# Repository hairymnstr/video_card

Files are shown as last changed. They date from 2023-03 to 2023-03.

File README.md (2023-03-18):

# ECB Video Card

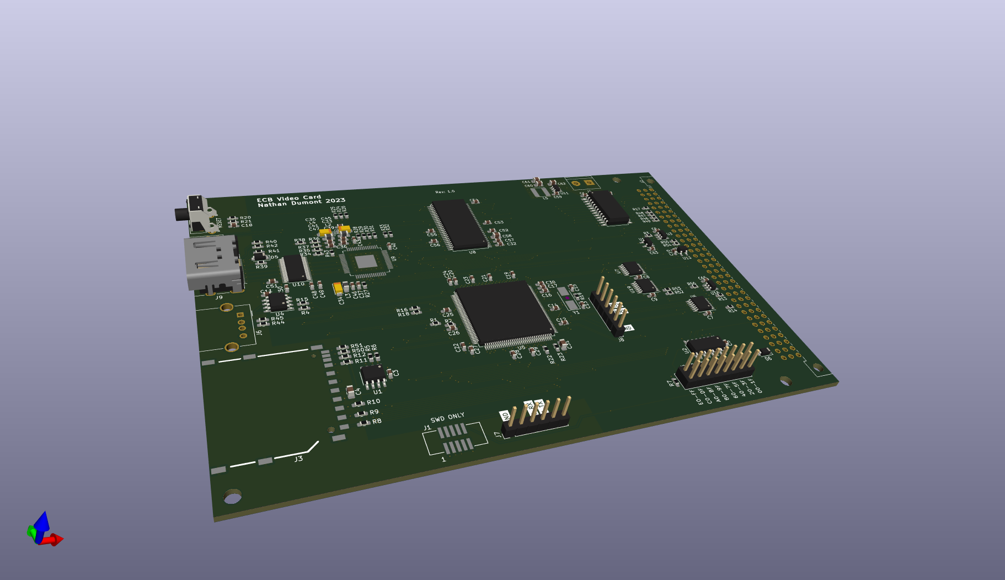
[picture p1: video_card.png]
A screenshot of a PCB with HDMI connector and various SMD chips


This is a project to create a working HDMI output video card for an ECB based 8 bit computer.  The general plan is to use this card with a Z80/Z180 based processor card and a backplane of some sort.  As far as I can see it's compatible with standard ECB layout and will probably work with other modern-retro computers.  It will probably work perfectly well as a standalone ARM based computer.

## Specs

A brief description of the board's features:

* STM32F429 ARM Cortex-M4 at 180MHz
* Hardware support for 2D DMA and graphics related operations
* 32MB (16M x 16) SDRAM at 90MHz for framebuffer and image storage
* USB host port via a single USB-A socket up to full-speed (12Mbps)
* SD card socket via SPI interface
* Two UART headers for 3.3V level interface
* 8 bit data bus interface
  * Mapped into 32 registers of the I/O address space
  * Selectable to any combination of the top 3 bits of the 8 bit IO bus
  * Support for interrupt generation including IEI/IEO cascading support
  * Can operate in Z80 mode-2 because the interrupt ack is mapped to an interrupt on the STM32

## Architecture

The core of the board is the STM32F429 which supports an LCD TFT controller which is outputting the hardware sync signals and the 3 colour channels as parallel data.  The pinout of the chip in use (only one I can currently get) limits the colour depth to 18 bits.  The LCD TFT interface is connected to a TI TFP410 HDMI/DVI transmitter chip which converts the parallel colour data and sync signals to differential data and clock for HDMI devices.  There's also an ESD protection chip on the HDMI output.

## Status

So far this is just a design, I've been messing around with these parts and designs for a few years but part availability and time have so far prevented me from building and testing it.  Hopefully in the near future I can get a board made and try it.

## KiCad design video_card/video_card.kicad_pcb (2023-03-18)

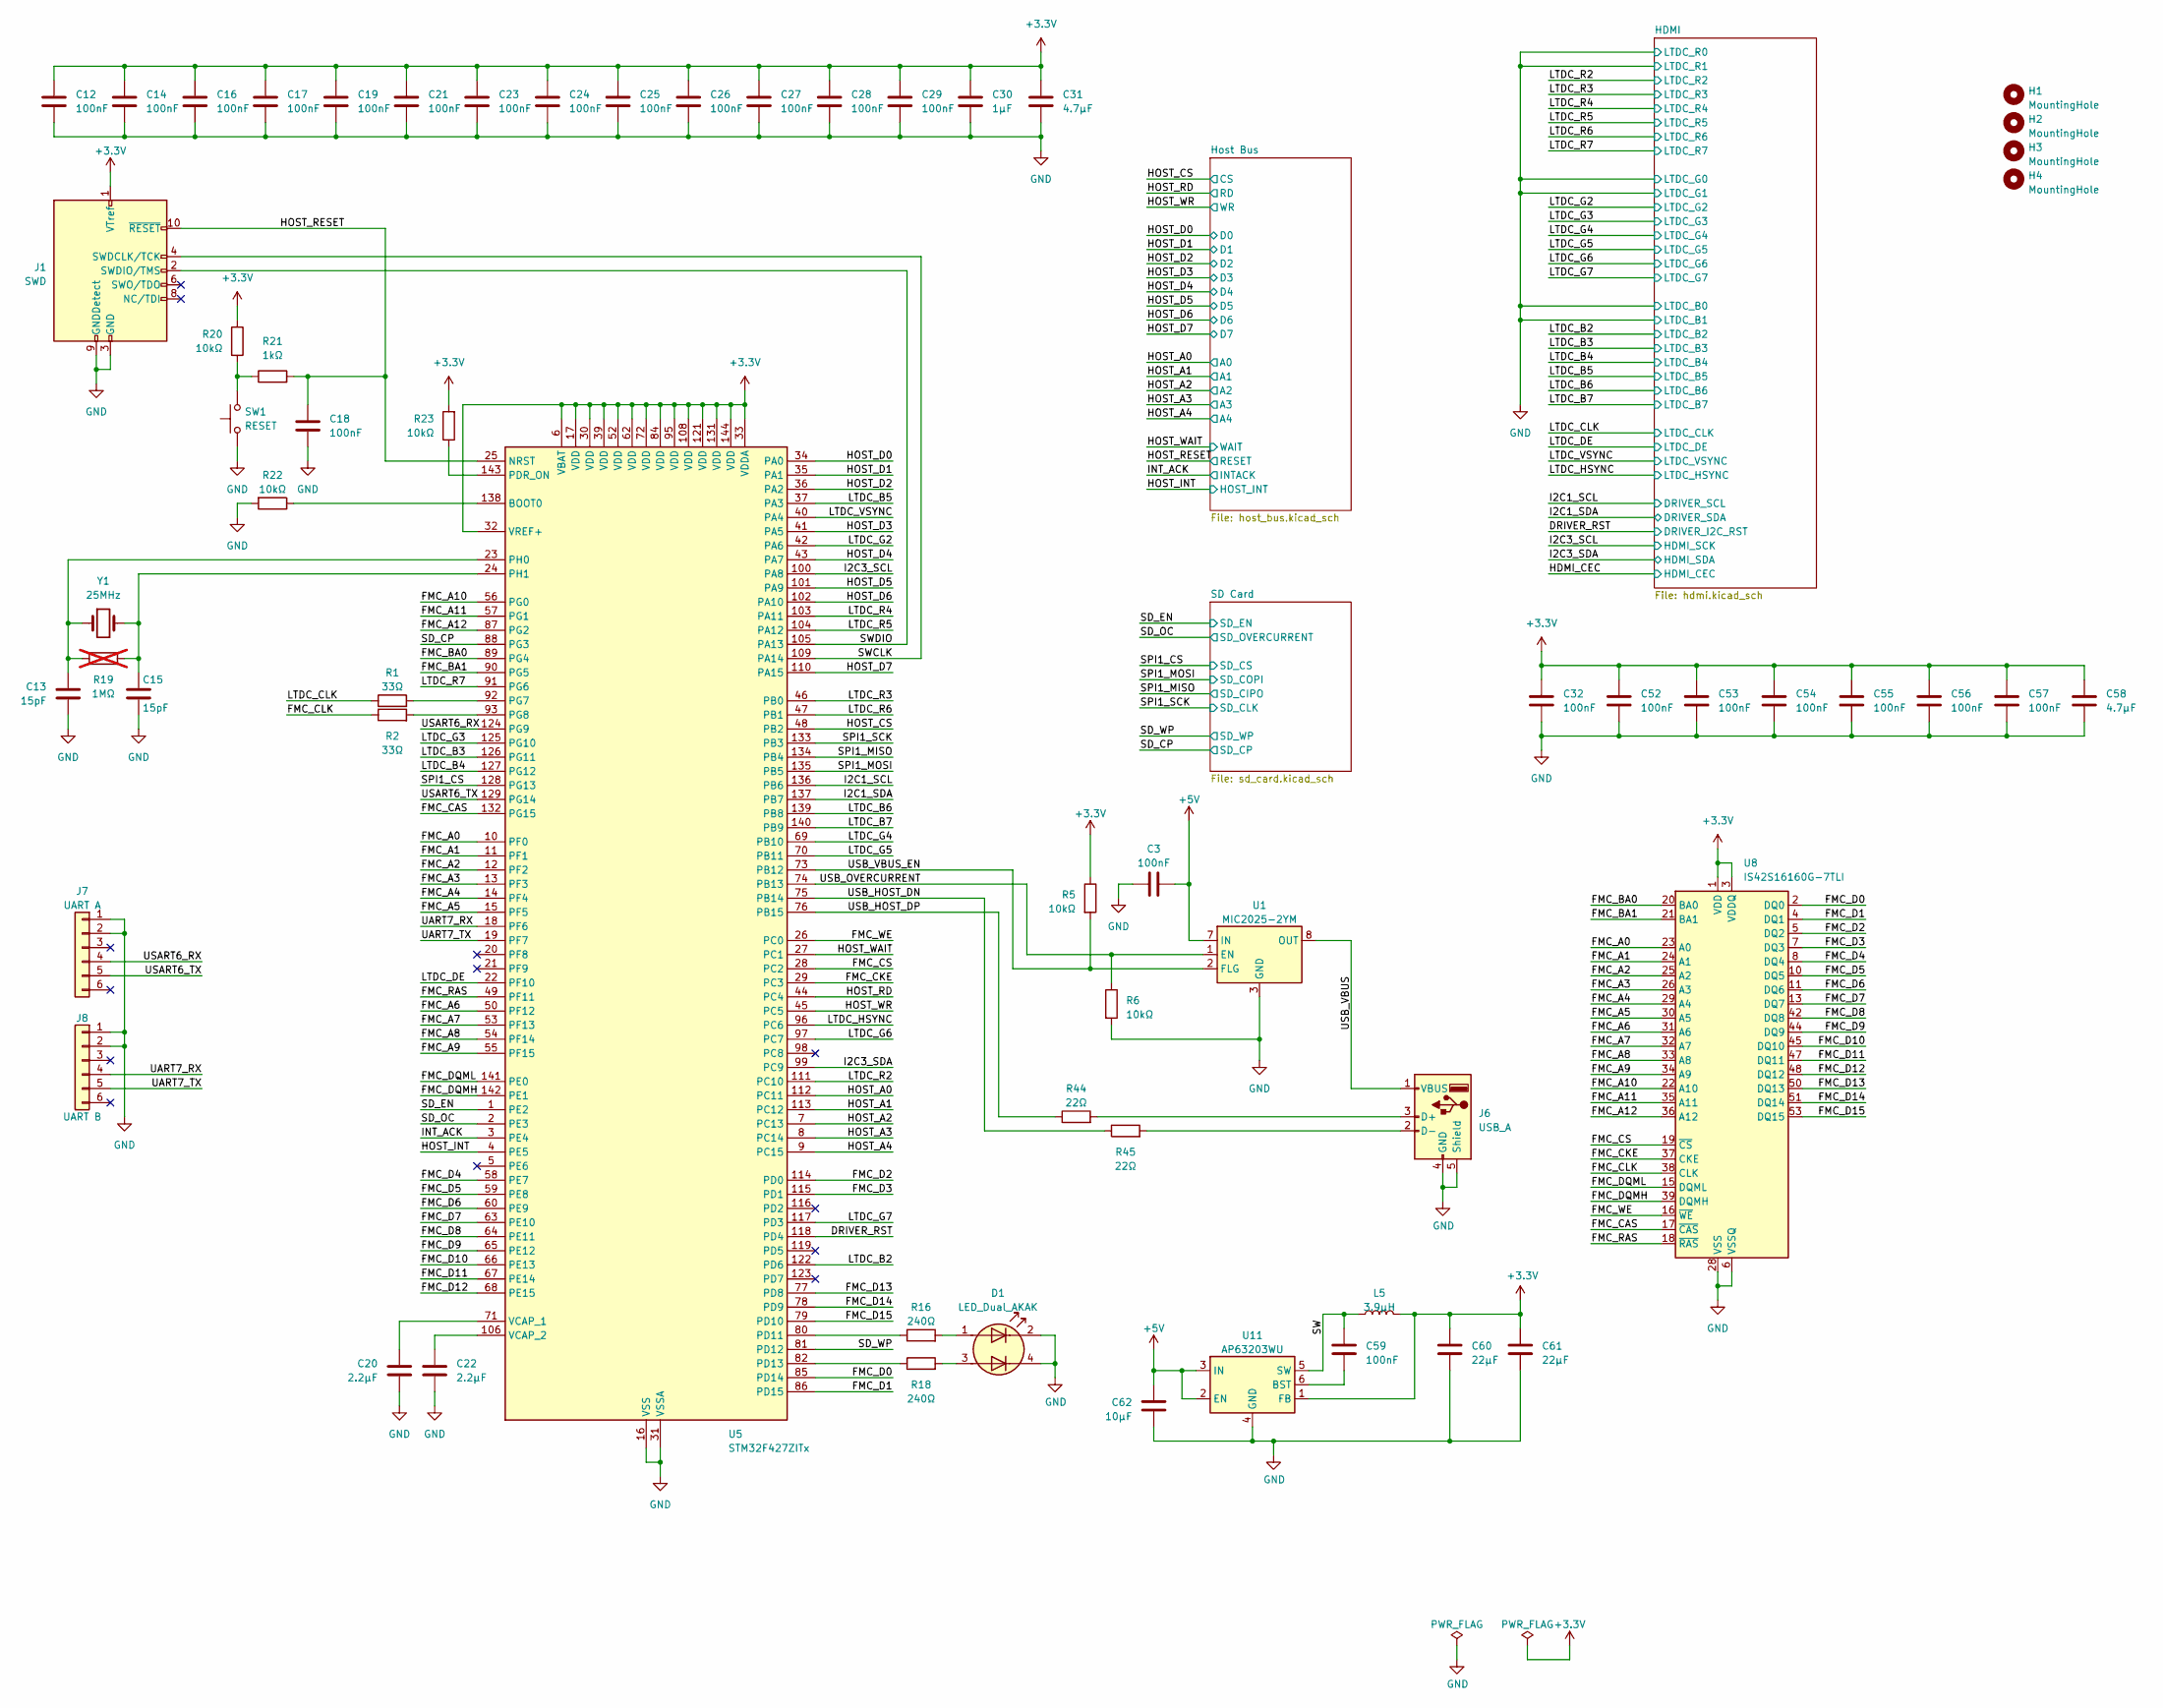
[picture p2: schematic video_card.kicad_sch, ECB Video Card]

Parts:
C3, C12, C14, C16, C17, C18, C19, C21, C23, C24, C25, C26, C27, C28, C29, C32, C52, C53, C54, C55, C56, C57, C59: 100nF; C_0603_1608Metric_Pad1.08x0.95mm_HandSolder; Part number Generic 0603 X7R 50V 10%
C13, C15: 15pF; C_0603_1608Metric_Pad1.08x0.95mm_HandSolder
C20, C22: 2.2µF; C_0603_1608Metric_Pad1.08x0.95mm_HandSolder
C30: 1µF; C_0603_1608Metric_Pad1.08x0.95mm_HandSolder
C31, C58: 4.7µF; C_0805_2012Metric_Pad1.18x1.45mm_HandSolder
C60, C61: 22µF; C_0805_2012Metric_Pad1.18x1.45mm_HandSolder
C62: 10µF; C_0805_2012Metric_Pad1.18x1.45mm_HandSolder
D1: LED_Dual_AKAK; LED_KINGBRIGHT_STACKED
H1, H2, H3, H4: MountingHole; MountingHole_3.2mm_M3
J1: SWD; SAMTEC_SHF-SM_5x2
J6: USB_A; USB_A_Molex_67643_Horizontal
J7: UART A; PinHeader_1x06_P2.54mm_Vertical
J8: UART B; PinHeader_1x06_P2.54mm_Vertical
L5: 3.9µH; Inductor_WE_LQS; Farnell 3517075
R1, R2: 33Ω; R_0603_1608Metric_Pad0.98x0.95mm_HandSolder
R5, R6, R20, R22, R23: 10kΩ; R_0603_1608Metric_Pad0.98x0.95mm_HandSolder
R16, R18: 240Ω; R_0603_1608Metric_Pad0.98x0.95mm_HandSolder
R19: 1MΩ; R_0603_1608Metric_Pad0.98x0.95mm_HandSolder; not fitted
R21: 1kΩ; R_0603_1608Metric_Pad0.98x0.95mm_HandSolder
R44, R45: 22Ω; R_0603_1608Metric_Pad0.98x0.95mm_HandSolder
SW1: RESET; SW_Tactile_SPST_Angled_PTS645Vx58-2LFS
U1: MIC2025-2YM; SOIC-8_3.9x4.9mm_P1.27mm
U5: STM32F427ZITx; LQFP-144_20x20mm_P0.5mm
U8: IS42S16160G-7TLI; TSOP-II-54_22.2x10.16mm_P0.8mm
U11: AP63203WU; TSOT-23-6
Y1: 25MHz; Crystal_SMD_Abracon_ABM3-2Pin_5.0x3.2mm_HandSoldering; Farnell 2101328

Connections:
/DRIVER_RST: U5.118 (PD4); also elsewhere on the board
/FMC_A0: U5.10 (PF0), U8.23 (A0)
/FMC_A1: U5.11 (PF1), U8.24 (A1)
/FMC_A2: U5.12 (PF2), U8.25 (A2)
/FMC_A3: U5.13 (PF3), U8.26 (A3)
/FMC_A4: U5.14 (PF4), U8.29 (A4)
/FMC_A5: U5.15 (PF5), U8.30 (A5)
/FMC_A6: U5.50 (PF12), U8.31 (A6)
/FMC_A7: U5.53 (PF13), U8.32 (A7)
/FMC_A8: U5.54 (PF14), U8.33 (A8)
/FMC_A9: U5.55 (PF15), U8.34 (A9)
/FMC_A10: U5.56 (PG0), U8.22 (A10)
/FMC_A11: U5.57 (PG1), U8.35 (A11)
/FMC_A12: U5.87 (PG2), U8.36 (A12)
/FMC_BA0: U5.89 (PG4), U8.20 (BA0)
/FMC_BA1: U5.90 (PG5), U8.21 (BA1)
/FMC_CAS: U5.132 (PG15), U8.17 (~CAS)
/FMC_CKE: U5.29 (PC3), U8.37 (CKE)
/FMC_CLK: R2.1, U8.38 (CLK)
/FMC_CS: U5.28 (PC2), U8.19 (~CS)
/FMC_D0: U5.85 (PD14), U8.2 (DQ0)
/FMC_D1: U5.86 (PD15), U8.4 (DQ1)
/FMC_D2: U5.114 (PD0), U8.5 (DQ2)
/FMC_D3: U5.115 (PD1), U8.7 (DQ3)
/FMC_D4: U5.58 (PE7), U8.8 (DQ4)
/FMC_D5: U5.59 (PE8), U8.10 (DQ5)
/FMC_D6: U5.60 (PE9), U8.11 (DQ6)
/FMC_D7: U5.63 (PE10), U8.13 (DQ7)
/FMC_D8: U5.64 (PE11), U8.42 (DQ8)
/FMC_D9: U5.65 (PE12), U8.44 (DQ9)
/FMC_D10: U5.66 (PE13), U8.45 (DQ10)
/FMC_D11: U5.67 (PE14), U8.47 (DQ11)
/FMC_D12: U5.68 (PE15), U8.48 (DQ12)
/FMC_D13: U5.77 (PD8), U8.50 (DQ13)
/FMC_D14: U5.78 (PD9), U8.51 (DQ14)
/FMC_D15: U5.79 (PD10), U8.53 (DQ15)
/FMC_DQMH: U5.142 (PE1), U8.39 (DQMH)
/FMC_DQML: U5.141 (PE0), U8.15 (DQML)
/FMC_RAS: U5.49 (PF11), U8.18 (~RAS)
/FMC_WE: U5.26 (PC0), U8.16 (~WE)
/HOST_A0: U5.112 (PC11); also elsewhere on the board
/HOST_A1: U5.113 (PC12); also elsewhere on the board
/HOST_A2: U5.7 (PC13); also elsewhere on the board
/HOST_A3: U5.8 (PC14); also elsewhere on the board
/HOST_A4: U5.9 (PC15); also elsewhere on the board
/HOST_CS: U5.48 (PB2); also elsewhere on the board
/HOST_D0: U5.34 (PA0); also elsewhere on the board
/HOST_D1: U5.35 (PA1); also elsewhere on the board
/HOST_D2: U5.36 (PA2); also elsewhere on the board
/HOST_D3: U5.41 (PA5); also elsewhere on the board
/HOST_D4: U5.43 (PA7); also elsewhere on the board
/HOST_D5: U5.101 (PA9); also elsewhere on the board
/HOST_D6: U5.102 (PA10); also elsewhere on the board
/HOST_D7: U5.110 (PA15); also elsewhere on the board
/HOST_INT: U5.4 (PE5); also elsewhere on the board
/HOST_RD: U5.44 (PC4); also elsewhere on the board
/HOST_RESET: C18.1, J1.10 (~RESET), R21.2, U5.25 (NRST); also elsewhere on the board
/HOST_WAIT: U5.27 (PC1); also elsewhere on the board
/HOST_WR: U5.45 (PC5); also elsewhere on the board
/I2C1_SCL: U5.136 (PB6); also elsewhere on the board
/I2C1_SDA: U5.137 (PB7); also elsewhere on the board
/I2C3_SCL: U5.100 (PA8); also elsewhere on the board
/I2C3_SDA: U5.99 (PC9); also elsewhere on the board
/INT_ACK: U5.3 (PE4); also elsewhere on the board
/LTDC_B2: U5.122 (PD6); also elsewhere on the board
/LTDC_B3: U5.126 (PG11); also elsewhere on the board
/LTDC_B4: U5.127 (PG12); also elsewhere on the board
/LTDC_B5: U5.37 (PA3); also elsewhere on the board
/LTDC_B6: U5.139 (PB8); also elsewhere on the board
/LTDC_B7: U5.140 (PB9); also elsewhere on the board
/LTDC_CLK: R1.1; also elsewhere on the board
/LTDC_DE: U5.22 (PF10); also elsewhere on the board
/LTDC_G2: U5.42 (PA6); also elsewhere on the board
/LTDC_G3: U5.125 (PG10); also elsewhere on the board
/LTDC_G4: U5.69 (PB10); also elsewhere on the board
/LTDC_G5: U5.70 (PB11); also elsewhere on the board
/LTDC_G6: U5.97 (PC7); also elsewhere on the board
/LTDC_G7: U5.117 (PD3); also elsewhere on the board
/LTDC_HSYNC: U5.96 (PC6); also elsewhere on the board
/LTDC_R2: U5.111 (PC10); also elsewhere on the board
/LTDC_R3: U5.46 (PB0); also elsewhere on the board
/LTDC_R4: U5.103 (PA11); also elsewhere on the board
/LTDC_R5: U5.104 (PA12); also elsewhere on the board
/LTDC_R6: U5.47 (PB1); also elsewhere on the board
/LTDC_R7: U5.91 (PG6); also elsewhere on the board
/LTDC_VSYNC: U5.40 (PA4); also elsewhere on the board
/SD_CP: U5.88 (PG3); also elsewhere on the board
/SD_WP: U5.81 (PD12); also elsewhere on the board
/SPI1_CS: U5.128 (PG13); also elsewhere on the board
/SPI1_MISO: U5.134 (PB4); also elsewhere on the board
/SPI1_MOSI: U5.135 (PB5); also elsewhere on the board
/SPI1_SCK: U5.133 (PB3); also elsewhere on the board
/SW: C59.1, L5.1, U11.5 (SW)
/SWCLK: J1.4 (SWDCLK/TCK), U5.109 (PA14)
/SWDIO: J1.2 (SWDIO/TMS), U5.105 (PA13)
/UART7_RX: J8.4, U5.18 (PF6)
/UART7_TX: J8.5, U5.19 (PF7)
/USART6_RX: J7.4, U5.124 (PG9)
/USART6_TX: J7.5, U5.129 (PG14)
/USB_HOST_DN: R45.1, U5.75 (PB14)
/USB_HOST_DP: R44.1, U5.76 (PB15)
GND: C3.1, C12.2, C13.2, C14.2, C15.2, C16.2, C17.2, C18.2, C19.2, C20.2, C21.2, C22.2, C23.2, C24.2, C25.2, C26.2, C27.2, C28.2, C29.2, C30.2, C31.2, C32.2, C52.2, C53.2, C54.2, C55.2, C56.2, C57.2, C58.2, C60.2, C61.2, C62.2, D1.2 (K1), D1.4 (K2), J1.3 (GND), J1.5 (GND), J1.9 (GNDDetect), J6.4 (GND), J6.5 (Shield), J7.1, J7.2, J8.1, J8.2, R6.2, R22.2, SW1.1, U1.3 (GND), U5.16 (VSS), U5.31 (VSSA), U5.38 (VSS), U5.51 (VSS), U5.61 (VSS), U5.83 (VSS), U5.94 (VSS), U5.107 (VSS), U5.120 (VSS), U5.130 (VSS), U8.6 (VSSQ), U8.12 (VSSQ), U8.28 (VSS), U8.41 (VSS), U8.46 (VSSQ), U8.52 (VSSQ), U8.54 (VSS), U11.4 (GND); also elsewhere on the board
unnamed: D1.1 (A1), R16.2
unnamed: D1.3 (A2), R18.2
unnamed: J6.3 (D+), R44.2
unnamed: J6.2 (D-), R45.2
unnamed: R20.2, R21.1, SW1.2
unnamed: R22.1, U5.138 (BOOT0)
unnamed: R16.1, U5.80 (PD11)
unnamed: R18.1, U5.82 (PD13)
unnamed: R23.1, U5.143 (PDR_ON)
unnamed: R1.2, U5.92 (PG7)
unnamed: R2.2, U5.93 (PG8)
unnamed: C13.1, R19.1, U5.23 (PH0), Y1.1
unnamed: C15.1, R19.2, U5.24 (PH1), Y1.2
unnamed: C20.1, U5.71 (VCAP_1)
unnamed: C22.1, U5.106 (VCAP_2)
unnamed: C59.2, U11.6 (BST)

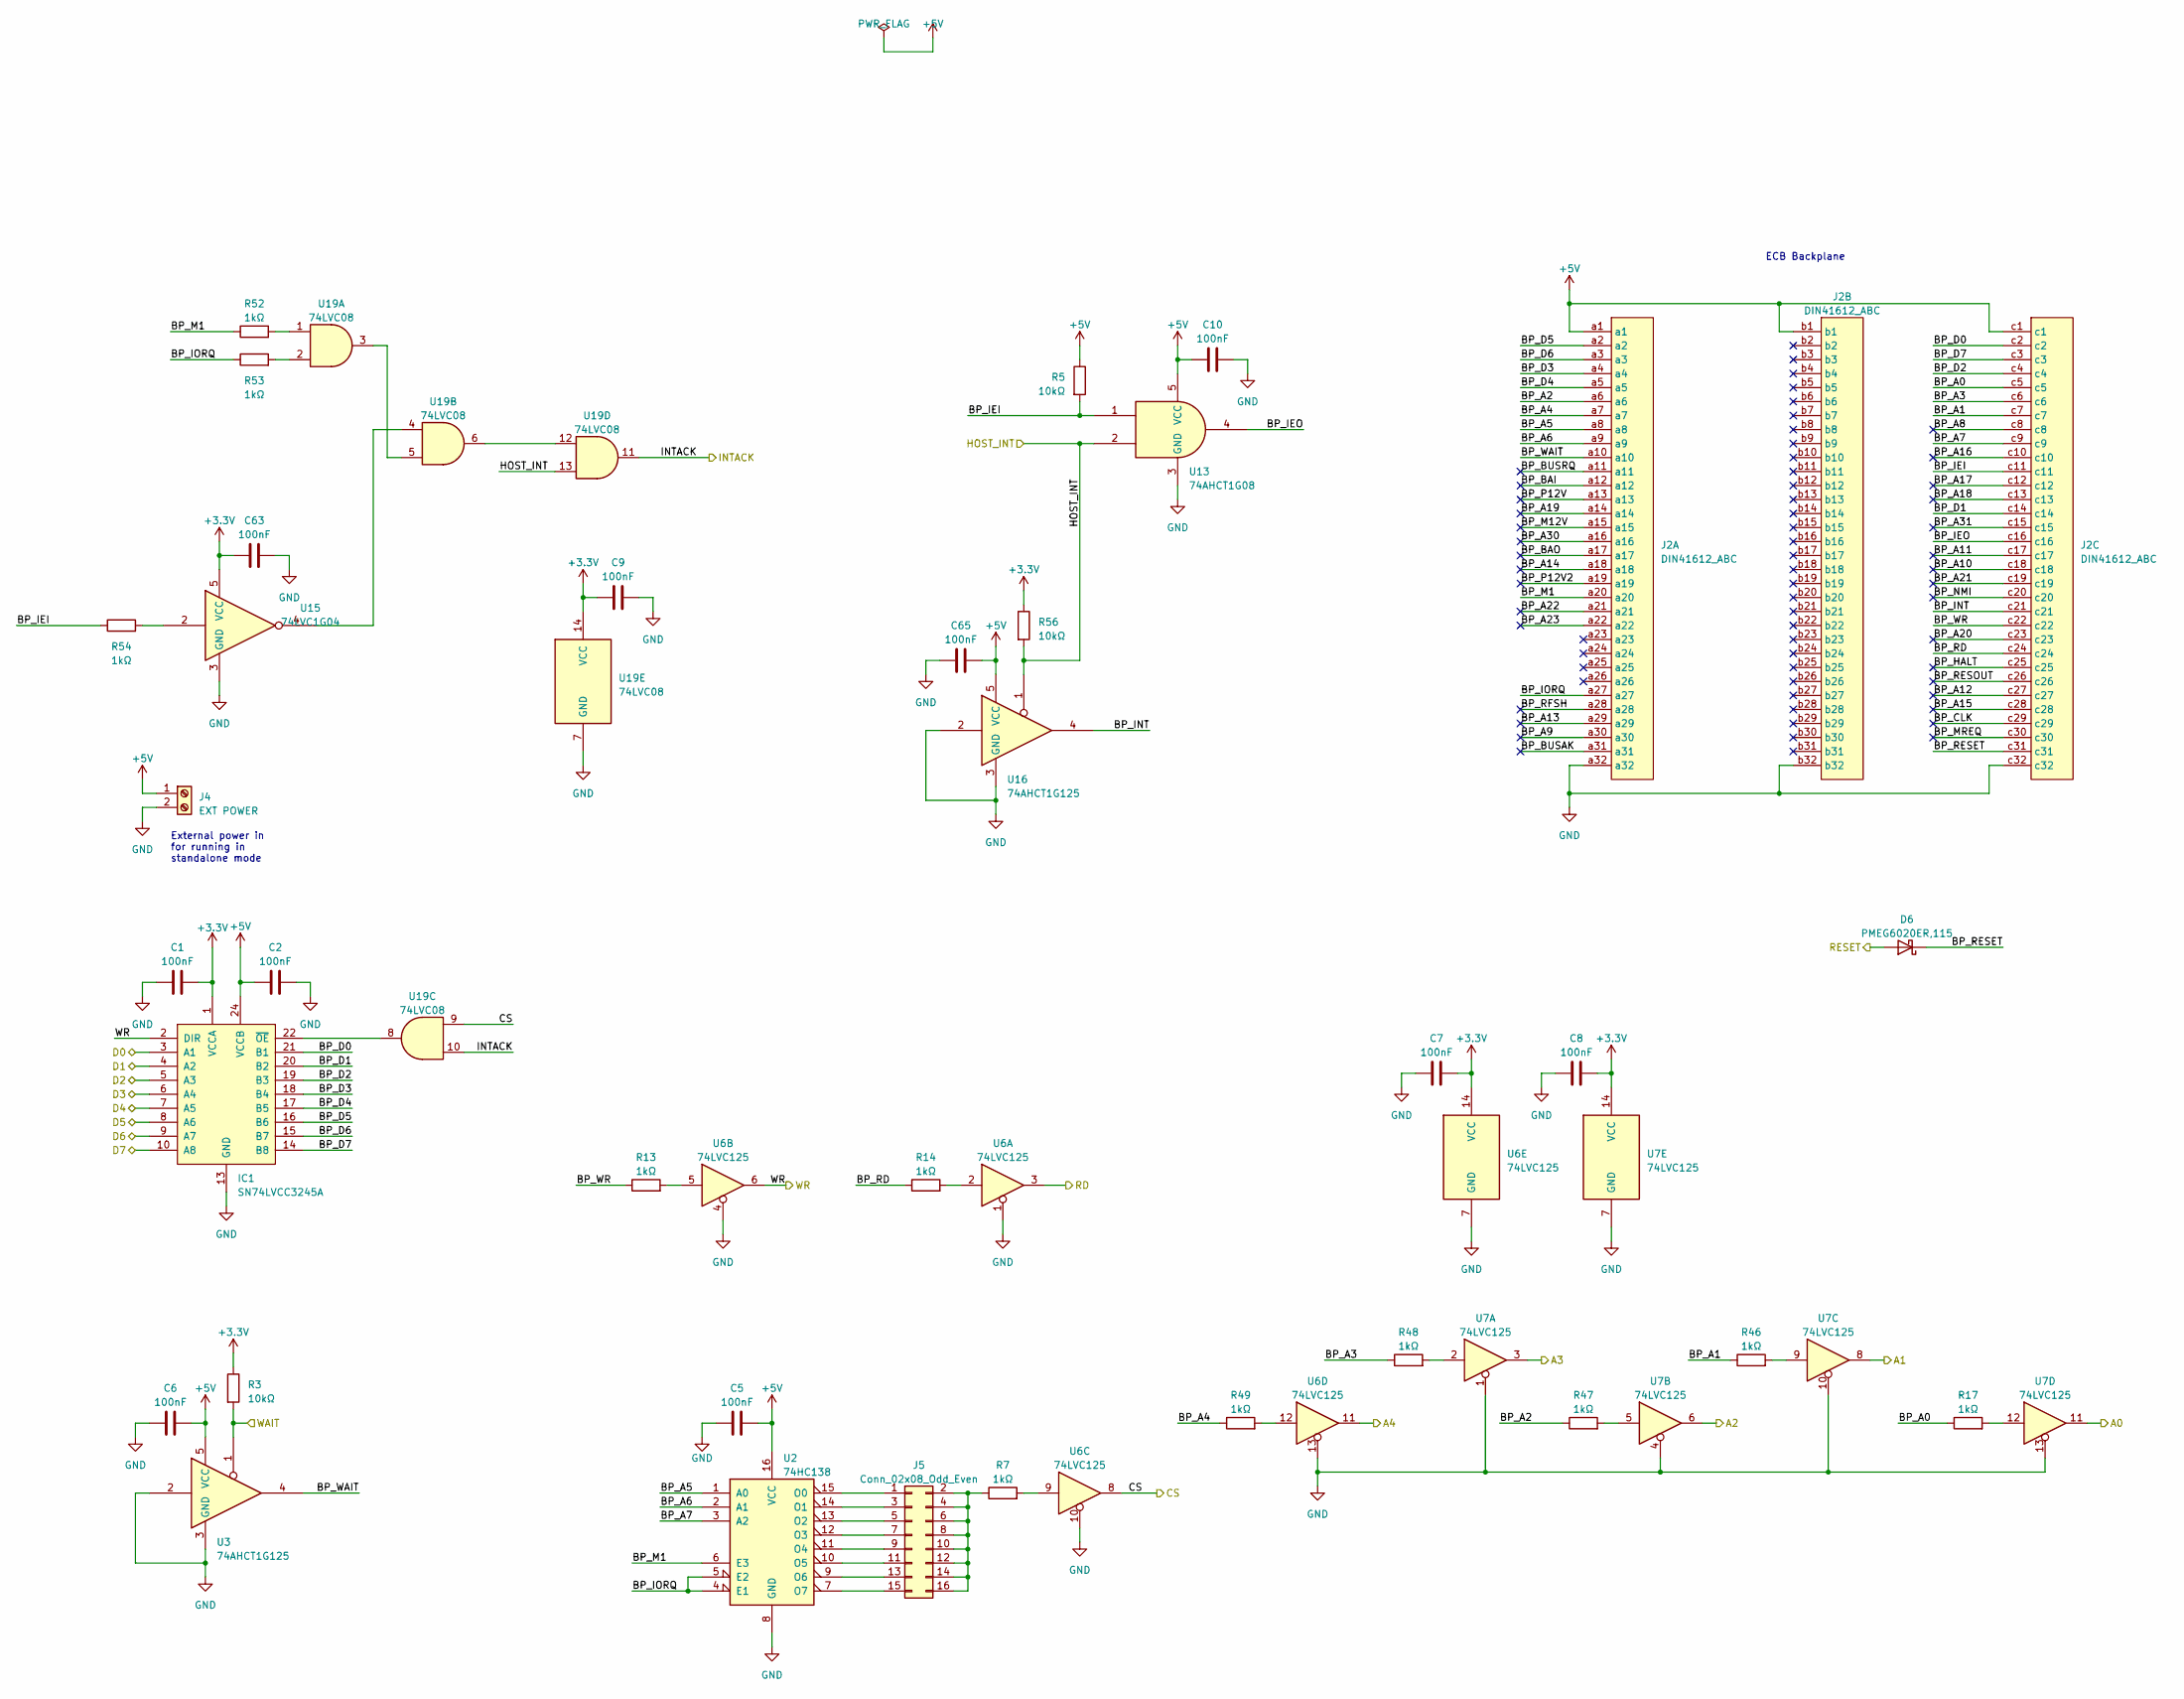
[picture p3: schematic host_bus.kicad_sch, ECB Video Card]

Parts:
C1, C2, C5, C6, C7, C8, C9, C10, C63, C65: 100nF; C_0603_1608Metric_Pad1.08x0.95mm_HandSolder; Part number Generic 0603 X7R 50V 10%
D6: PMEG6020ER,115; D_SOD-123
IC1: SN74LVCC3245A; SOIC-24W_7.5x15.4mm_P1.27mm
J2: DIN41612_ABC; DIN41612_R_3x32_Male_Horizontal_THT
J4: EXT POWER; TerminalBlock_bornier-2_P5.08mm
J5: Conn_02x08_Odd_Even; PinHeader_2x08_P2.54mm_Vertical
R3, R5, R56: 10kΩ; R_0603_1608Metric_Pad0.98x0.95mm_HandSolder
R7, R13, R14, R17, R46, R47, R48, R49, R52, R53, R54: 1kΩ; R_0603_1608Metric_Pad0.98x0.95mm_HandSolder
U2: 74HC138; SOIC-16_3.9x9.9mm_P1.27mm
U3, U16: 74AHCT1G125; SOT-23-5_HandSoldering
U6, U7: 74LVC125; TSSOP-14_4.4x5mm_P0.65mm
U13: 74AHCT1G08; SOT-23-5_HandSoldering
U15: 74LVC1G04; SOT-23-5_HandSoldering
U19: 74LVC08; TSSOP-14_4.4x5mm_P0.65mm

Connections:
/HOST_A0: U7.11; also elsewhere on the board
/HOST_A1: U7.8; also elsewhere on the board
/HOST_A2: U7.6; also elsewhere on the board
/HOST_A3: U7.3; also elsewhere on the board
/HOST_A4: U6.11; also elsewhere on the board
/HOST_CS: U6.8, U19.9; also elsewhere on the board
/HOST_D0: IC1.3 (A1); also elsewhere on the board
/HOST_D1: IC1.4 (A2); also elsewhere on the board
/HOST_D2: IC1.5 (A3); also elsewhere on the board
/HOST_D3: IC1.6 (A4); also elsewhere on the board
/HOST_D4: IC1.7 (A5); also elsewhere on the board
/HOST_D5: IC1.8 (A6); also elsewhere on the board
/HOST_D6: IC1.9 (A7); also elsewhere on the board
/HOST_D7: IC1.10 (A8); also elsewhere on the board
/HOST_INT: R56.2, U13.2, U16.1, U19.13; also elsewhere on the board
/HOST_RD: U6.3; also elsewhere on the board
/HOST_RESET: D6.2 (A); also elsewhere on the board
/HOST_WAIT: R3.2, U3.1; also elsewhere on the board
/HOST_WR: IC1.2 (DIR), U6.6; also elsewhere on the board
/Host Bus/BP_A0: J2.c5, R17.1
/Host Bus/BP_A1: J2.c7, R46.1
/Host Bus/BP_A2: J2.a6, R47.1
/Host Bus/BP_A3: J2.c6, R48.1
/Host Bus/BP_A4: J2.a7, R49.1
/Host Bus/BP_A5: J2.a8, U2.1 (A0)
/Host Bus/BP_A6: J2.a9, U2.2 (A1)
/Host Bus/BP_A7: J2.c9, U2.3 (A2)
/Host Bus/BP_A8: J2.c8
/Host Bus/BP_A9: J2.a30
/Host Bus/BP_A10: J2.c18
/Host Bus/BP_A11: J2.c17
/Host Bus/BP_A12: J2.c27
/Host Bus/BP_A13: J2.a29
/Host Bus/BP_A14: J2.a18
/Host Bus/BP_A15: J2.c28
/Host Bus/BP_A16: J2.c10
/Host Bus/BP_A17: J2.c12
/Host Bus/BP_A18: J2.c13
/Host Bus/BP_A19: J2.a14
/Host Bus/BP_A20: J2.c23
/Host Bus/BP_A21: J2.c19
/Host Bus/BP_A22: J2.a21
/Host Bus/BP_A23: J2.a22
/Host Bus/BP_A30: J2.a16
/Host Bus/BP_A31: J2.c15
/Host Bus/BP_BAI: J2.a12
/Host Bus/BP_BAO: J2.a17
/Host Bus/BP_BUSAK: J2.a31
/Host Bus/BP_BUSRQ: J2.a11
/Host Bus/BP_CLK: J2.c29
/Host Bus/BP_D0: IC1.21 (B1), J2.c2
/Host Bus/BP_D1: IC1.20 (B2), J2.c14
/Host Bus/BP_D2: IC1.19 (B3), J2.c4
/Host Bus/BP_D3: IC1.18 (B4), J2.a4
/Host Bus/BP_D4: IC1.17 (B5), J2.a5
/Host Bus/BP_D5: IC1.16 (B6), J2.a2
/Host Bus/BP_D6: IC1.15 (B7), J2.a3
/Host Bus/BP_D7: IC1.14 (B8), J2.c3
/Host Bus/BP_HALT: J2.c25
/Host Bus/BP_IEO: J2.c16, U13.4
/Host Bus/BP_INT: J2.c21, U16.4
/Host Bus/BP_IORQ: J2.a27, R53.1, U2.4 (E1), U2.5 (E2)
/Host Bus/BP_M1: J2.a20, R52.1, U2.6 (E3)
/Host Bus/BP_M12V: J2.a15
/Host Bus/BP_MREQ: J2.c30
/Host Bus/BP_NMI: J2.c20
/Host Bus/BP_P12V: J2.a13
/Host Bus/BP_P12V2: J2.a19
/Host Bus/BP_RD: J2.c24, R14.1
/Host Bus/BP_RESET: D6.1 (K), J2.c31
/Host Bus/BP_RESOUT: J2.c26
/Host Bus/BP_RFSH: J2.a28
/Host Bus/BP_WAIT: J2.a10, U3.4
/Host Bus/BP_WR: J2.c22, R13.1
/INT_ACK: U19.10, U19.11; also elsewhere on the board
GND: C1.1, C2.2, C5.1, C6.1, C7.1, C8.1, C9.2, C10.2, C63.2, C65.1, IC1.11 (GND), IC1.12 (GND), IC1.13 (GND), J2.a32, J2.b32, J2.c32, J4.2, U2.8 (GND), U3.2, U3.3 (GND), U6.1, U6.4, U6.7 (GND), U6.10, U6.13, U7.1, U7.4, U7.7 (GND), U7.10, U7.13, U13.3 (GND), U15.3 (GND), U16.2, U16.3 (GND), U19.7 (GND); also elsewhere on the board
unnamed: IC1.22 (~OE), U19.8
unnamed: J5.1, U2.15 (O0)
unnamed: J5.3, U2.14 (O1)
unnamed: J5.5, U2.13 (O2)
unnamed: J5.7, U2.12 (O3)
unnamed: J5.9, U2.11 (O4)
unnamed: J5.2, J5.4, J5.6, J5.8, J5.10, J5.12, J5.14, J5.16, R7.1
unnamed: J5.11, U2.10 (O5)
unnamed: J5.13, U2.9 (O6)
unnamed: J5.15, U2.7 (O7)
unnamed: R7.2, U6.9
unnamed: R13.2, U6.5
unnamed: R14.2, U6.2
unnamed: R17.2, U7.12
unnamed: R46.2, U7.9
unnamed: R47.2, U7.5
unnamed: R48.2, U7.2
unnamed: R49.2, U6.12
unnamed: R52.2, U19.1
unnamed: R53.2, U19.2
unnamed: R54.2, U15.2
unnamed: U15.4, U19.4
unnamed: U19.3, U19.5
unnamed: U19.6, U19.12

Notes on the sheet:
ECB Backplane
External power in for running in standalone mode

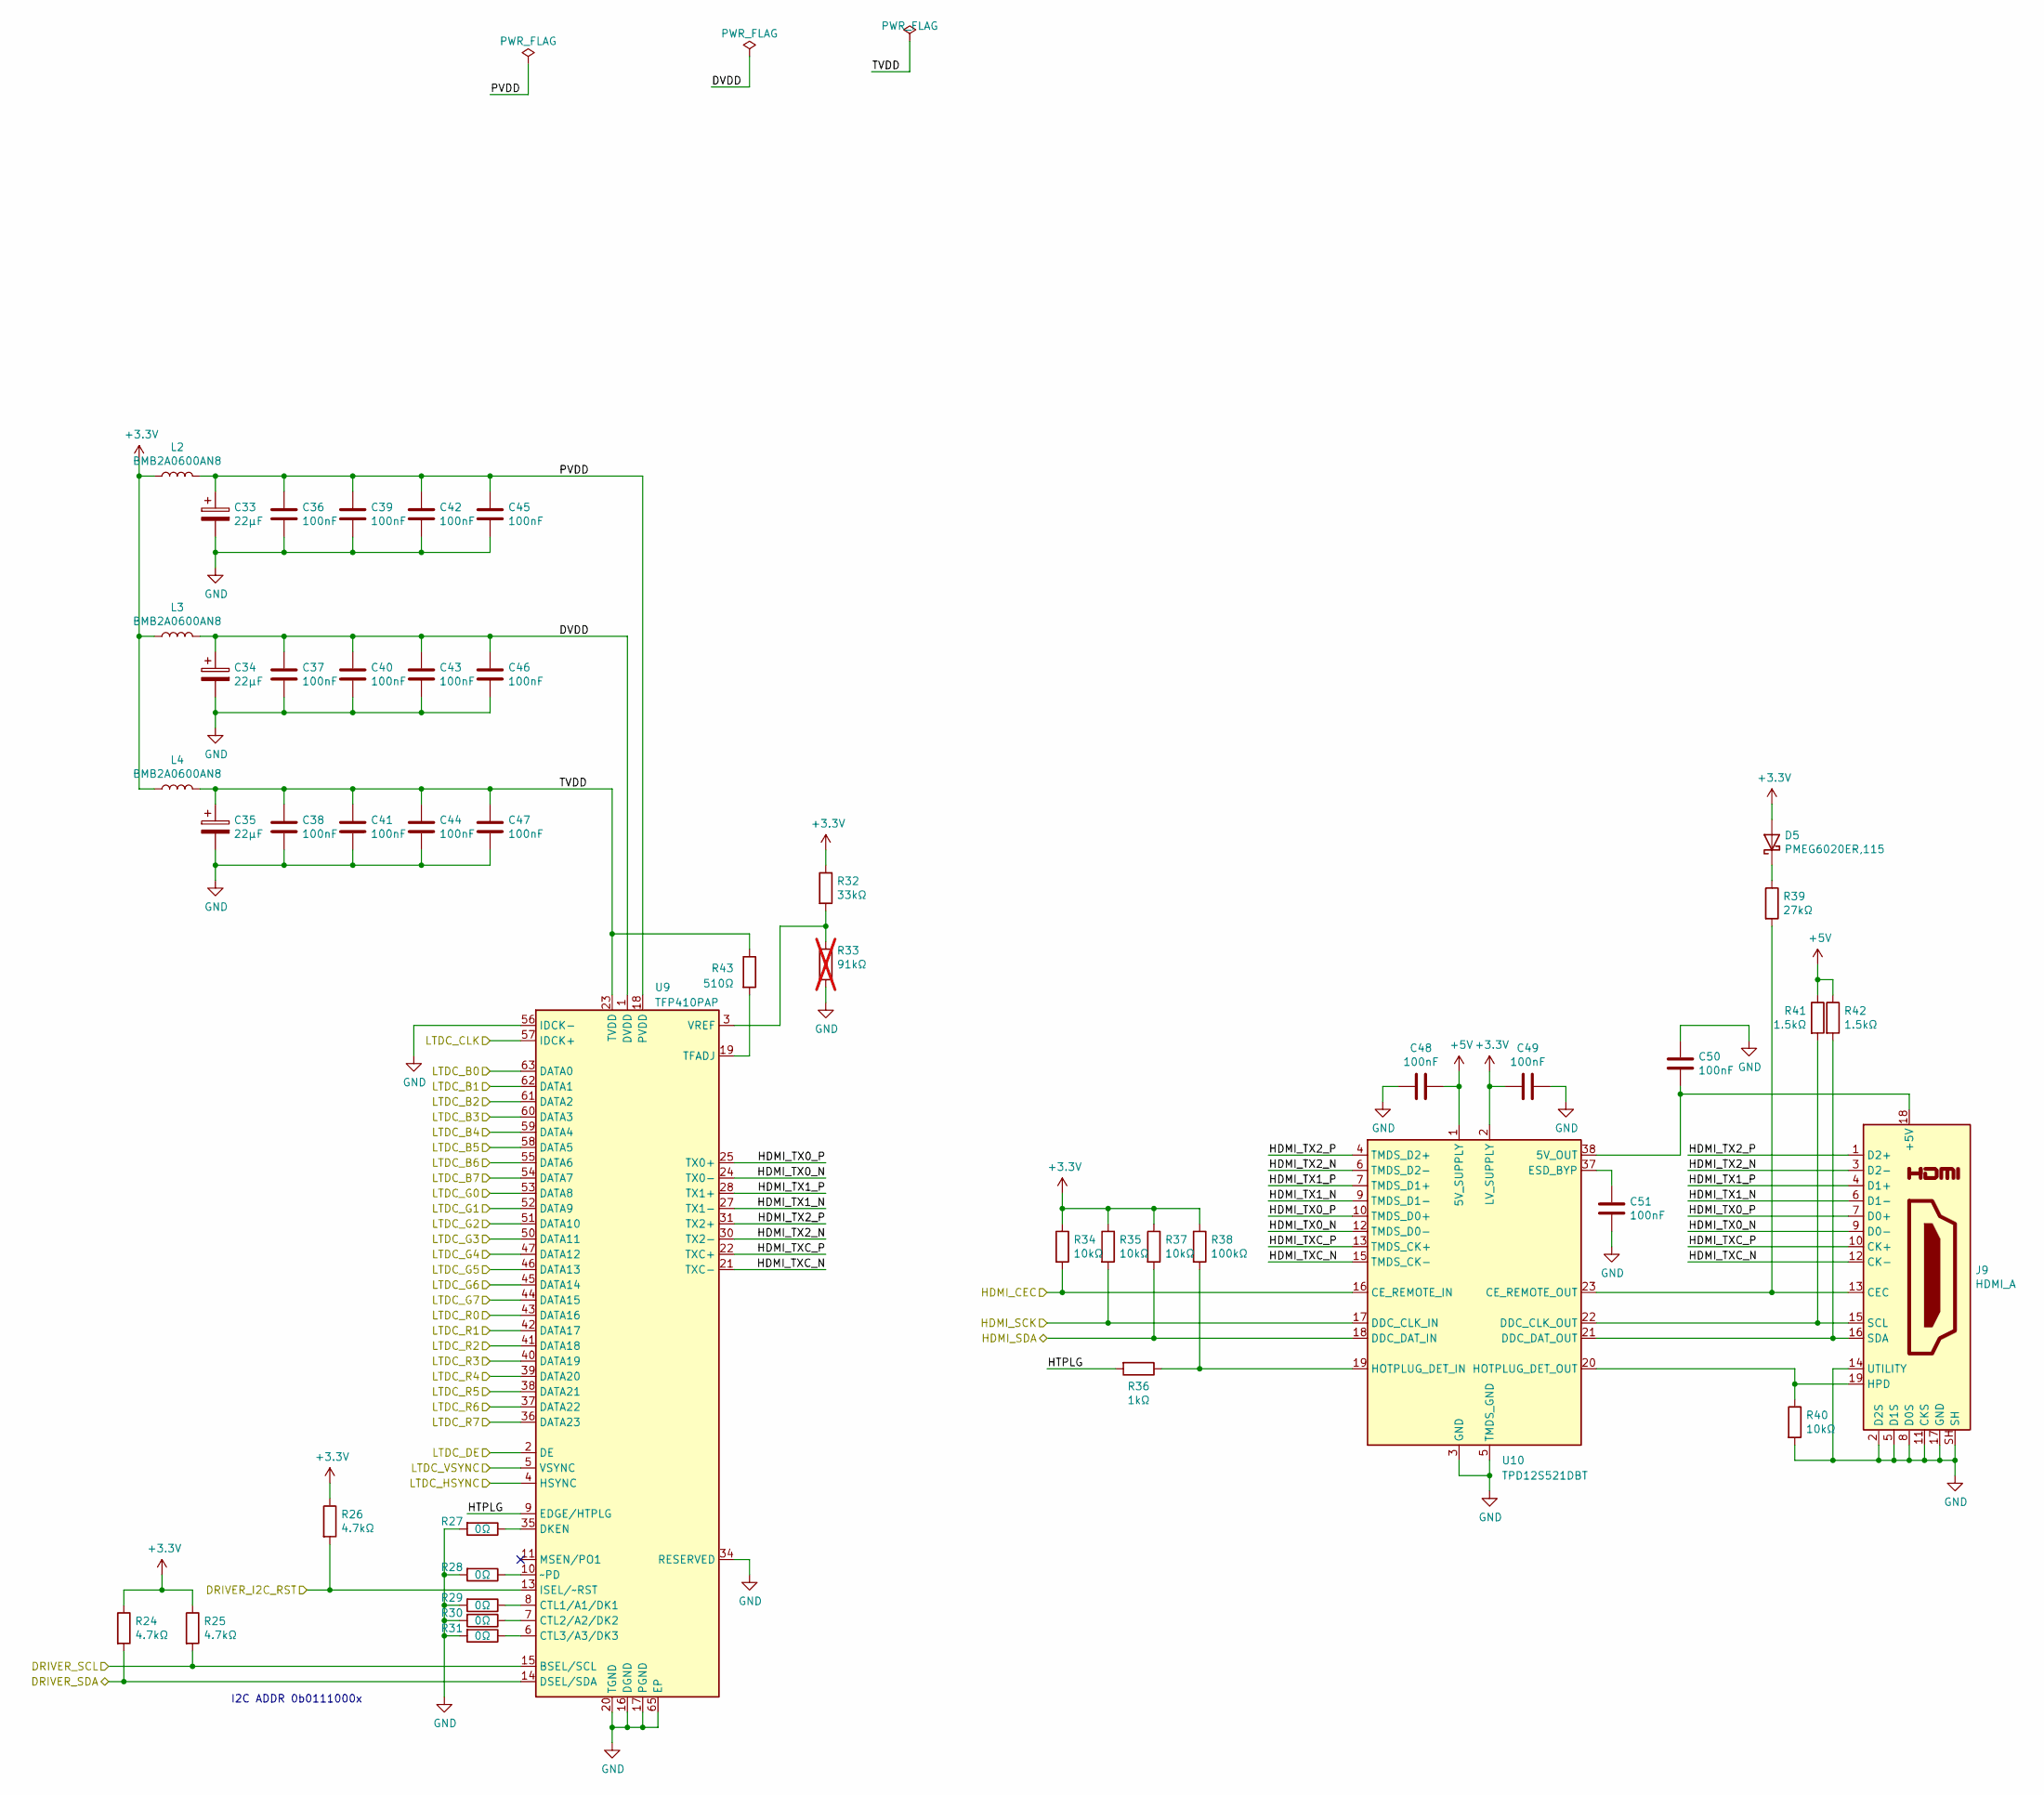
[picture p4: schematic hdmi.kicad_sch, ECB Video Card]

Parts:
C33, C34, C35: 22µF; CP_EIA-3216-10_Kemet-I_Pad1.58x1.35mm_HandSolder; Farnell 1457420
C36, C37, C38, C39, C40, C41, C42, C43, C44, C45, C46, C47, C48, C49, C50, C51: 100nF; C_0603_1608Metric_Pad1.08x0.95mm_HandSolder; Part number Generic 0603 X7R 50V 10%
D5: PMEG6020ER,115; D_SOD-123
J9: HDMI_A; HDMI_A_Molex_208658-1001_Horizontal
L2, L3, L4: BMB2A0600AN8; L_0805_2012Metric_Pad1.05x1.20mm_HandSolder
R24, R25, R26: 4.7kΩ; R_0603_1608Metric_Pad0.98x0.95mm_HandSolder
R27, R28, R29, R30, R31: 0Ω; R_0603_1608Metric_Pad0.98x0.95mm_HandSolder
R32: 33kΩ; R_0603_1608Metric_Pad0.98x0.95mm_HandSolder
R33: 91kΩ; R_0603_1608Metric_Pad0.98x0.95mm_HandSolder; not fitted
R34, R35, R37, R40: 10kΩ; R_0603_1608Metric_Pad0.98x0.95mm_HandSolder
R36: 1kΩ; R_0603_1608Metric_Pad0.98x0.95mm_HandSolder
R38: 100kΩ; R_0603_1608Metric_Pad0.98x0.95mm_HandSolder
R39: 27kΩ; R_0603_1608Metric_Pad0.98x0.95mm_HandSolder
R41, R42: 1.5kΩ; R_0603_1608Metric_Pad0.98x0.95mm_HandSolder
R43: 510Ω; R_0603_1608Metric_Pad0.98x0.95mm_HandSolder
U9: TFP410PAP; QFP-64_10x10_P0.5mm-1EP8x8-Mask5x5
U10: TPD12S521DBT; TSSOP-38_4.4x9.7mm_P0.5mm

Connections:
/DRIVER_RST: R26.2, U9.13 (ISEL/~RST); also elsewhere on the board
/HDMI/DVDD: C34.1, C37.1, C40.1, C43.1, C46.1, L3.2, U9.1 (DVDD), U9.12 (DVDD), U9.33 (DVDD)
/HDMI/HDMI_TX0_N: J9.9 (D0-), U9.24 (TX0-), U10.12 (TMDS_D0-), U10.27 (TMDS_D0-)
/HDMI/HDMI_TX0_P: J9.7 (D0+), U9.25 (TX0+), U10.10 (TMDS_D0+), U10.29 (TMDS_D0+)
/HDMI/HDMI_TX1_N: J9.6 (D1-), U9.27 (TX1-), U10.9 (TMDS_D1-), U10.30 (TMDS_D1-)
/HDMI/HDMI_TX1_P: J9.4 (D1+), U9.28 (TX1+), U10.7 (TMDS_D1+), U10.32 (TMDS_D1+)
/HDMI/HDMI_TX2_N: J9.3 (D2-), U9.30 (TX2-), U10.6 (TMDS_D2-), U10.33 (TMDS_D2-)
/HDMI/HDMI_TX2_P: J9.1 (D2+), U9.31 (TX2+), U10.4 (TMDS_D2+), U10.35 (TMDS_D2+)
/HDMI/HDMI_TXC_N: J9.12 (CK-), U9.21 (TXC-), U10.15 (TMDS_CK-), U10.24 (TMDS_CK-)
/HDMI/HDMI_TXC_P: J9.10 (CK+), U9.22 (TXC+), U10.13 (TMDS_CK+), U10.26 (TMDS_CK+)
/HDMI/HTPLG: R36.2, U9.9 (EDGE/HTPLG)
/HDMI/PVDD: C33.1, C36.1, C39.1, C42.1, C45.1, L2.2, U9.18 (PVDD)
/HDMI/TVDD: C35.1, C38.1, C41.1, C44.1, C47.1, L4.2, R43.1, U9.23 (TVDD), U9.29 (TVDD)
/HDMI_CEC: R34.2, U10.16 (CE_REMOTE_IN)
/I2C1_SCL: R25.2, U9.15 (BSEL/SCL); also elsewhere on the board
/I2C1_SDA: R24.2, U9.14 (DSEL/SDA); also elsewhere on the board
/I2C3_SCL: R35.2, U10.17 (DDC_CLK_IN); also elsewhere on the board
/I2C3_SDA: R37.2, U10.18 (DDC_DAT_IN); also elsewhere on the board
/LTDC_B2: U9.61 (DATA2); also elsewhere on the board
/LTDC_B3: U9.60 (DATA3); also elsewhere on the board
/LTDC_B4: U9.59 (DATA4); also elsewhere on the board
/LTDC_B5: U9.58 (DATA5); also elsewhere on the board
/LTDC_B6: U9.55 (DATA6); also elsewhere on the board
/LTDC_B7: U9.54 (DATA7); also elsewhere on the board
/LTDC_CLK: U9.57 (IDCK+); also elsewhere on the board
/LTDC_DE: U9.2 (DE); also elsewhere on the board
/LTDC_G2: U9.51 (DATA10); also elsewhere on the board
/LTDC_G3: U9.50 (DATA11); also elsewhere on the board
/LTDC_G4: U9.47 (DATA12); also elsewhere on the board
/LTDC_G5: U9.46 (DATA13); also elsewhere on the board
/LTDC_G6: U9.45 (DATA14); also elsewhere on the board
/LTDC_G7: U9.44 (DATA15); also elsewhere on the board
/LTDC_HSYNC: U9.4 (HSYNC); also elsewhere on the board
/LTDC_R2: U9.41 (DATA18); also elsewhere on the board
/LTDC_R3: U9.40 (DATA19); also elsewhere on the board
/LTDC_R4: U9.39 (DATA20); also elsewhere on the board
/LTDC_R5: U9.38 (DATA21); also elsewhere on the board
/LTDC_R6: U9.37 (DATA22); also elsewhere on the board
/LTDC_R7: U9.36 (DATA23); also elsewhere on the board
/LTDC_VSYNC: U9.5 (VSYNC); also elsewhere on the board
GND: C33.2, C34.2, C35.2, C36.2, C37.2, C38.2, C39.2, C40.2, C41.2, C42.2, C43.2, C44.2, C45.2, C46.2, C47.2, C48.2, C49.1, C50.1, C51.2, J9.2 (D2S), J9.5 (D1S), J9.8 (D0S), J9.11 (CKS), J9.14 (UTILITY), J9.17 (GND), J9.SH, R27.2, R28.2, R29.2, R30.2, R31.2, R33.2, R40.2, U9.16 (DGND), U9.17 (PGND), U9.20 (TGND), U9.26 (TGND), U9.32 (TGND), U9.34 (RESERVED), U9.42 (DATA17), U9.43 (DATA16), U9.48 (DGND), U9.52 (DATA9), U9.53 (DATA8), U9.56 (IDCK-), U9.62 (DATA1), U9.63 (DATA0), U9.64 (DGND), U9.65 (EP), U10.3 (GND), U10.5 (TMDS_GND), U10.8 (TMDS_GND), U10.11 (TMDS_GND), U10.14 (TMDS_GND), U10.25 (TMDS_GND), U10.28 (TMDS_GND), U10.31 (TMDS_GND), U10.34 (TMDS_GND), U10.36 (GND); also elsewhere on the board
unnamed: D5.1 (K), R39.1
unnamed: C50.2, J9.18 (+5V), U10.38 (5V_OUT)
unnamed: J9.13 (CEC), R39.2, U10.23 (CE_REMOTE_OUT)
unnamed: J9.19 (HPD), R40.1, U10.20 (HOTPLUG_DET_OUT)
unnamed: J9.15 (SCL), R41.2, U10.22 (DDC_CLK_OUT)
unnamed: J9.16 (SDA), R42.2, U10.21 (DDC_DAT_OUT)
unnamed: R29.1, U9.8 (CTL1/A1/DK1)
unnamed: R30.1, U9.7 (CTL2/A2/DK2)
unnamed: R31.1, U9.6 (CTL3/A3/DK3)
unnamed: R27.1, U9.35 (DKEN)
unnamed: R43.2, U9.19 (TFADJ)
unnamed: R32.2, R33.1, U9.3 (VREF)
unnamed: R28.1, U9.10 (~PD)
unnamed: C51.1, U10.37 (ESD_BYP)
unnamed: R36.1, R38.2, U10.19 (HOTPLUG_DET_IN)

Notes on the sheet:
I2C ADDR 0b0111000x

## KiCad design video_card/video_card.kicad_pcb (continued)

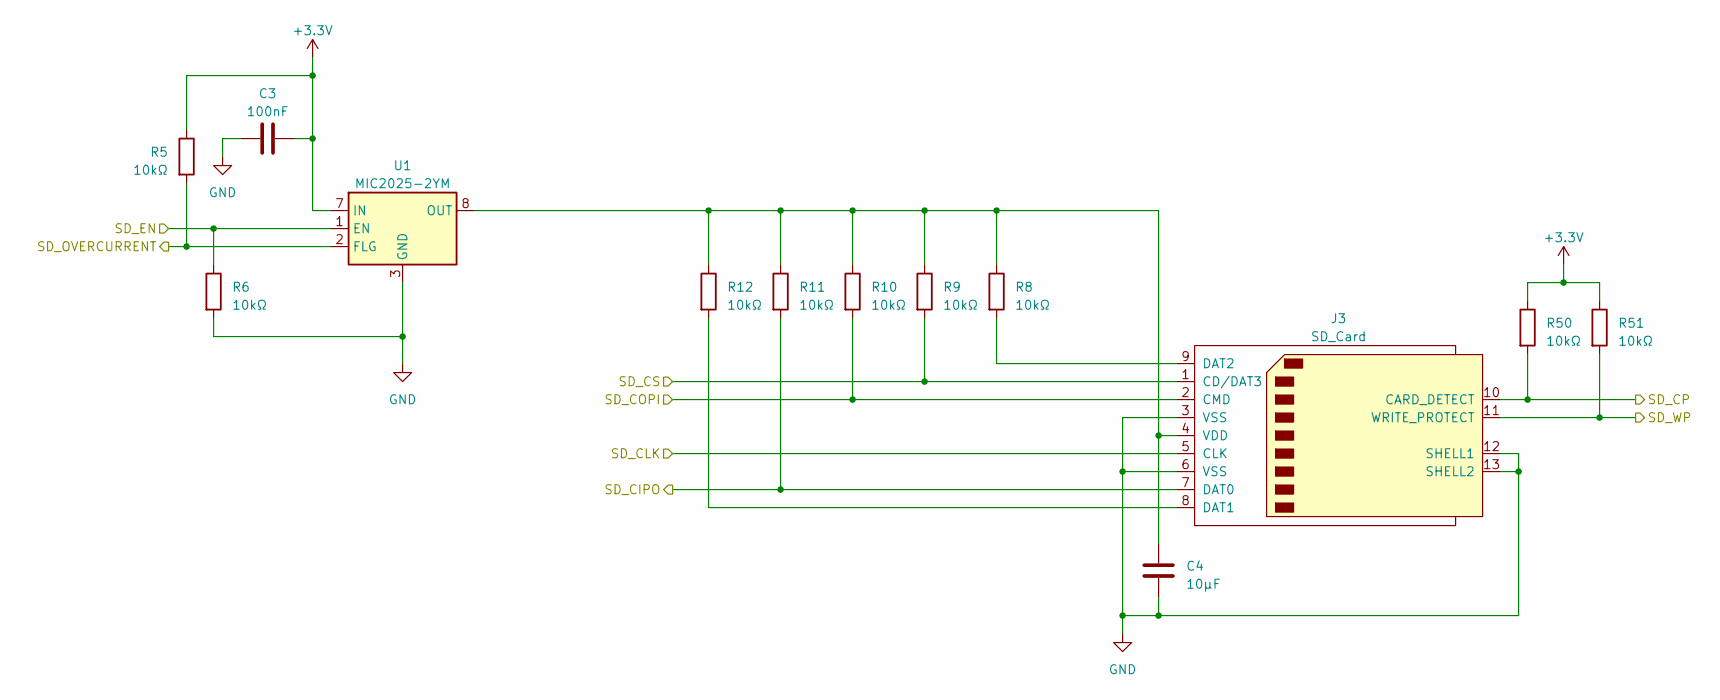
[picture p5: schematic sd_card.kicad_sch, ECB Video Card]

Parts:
C3: 100nF; C_0603_1608Metric_Pad1.08x0.95mm_HandSolder; Part number Generic 0603 X7R 50V 10%
C4: 10µF; C_0805_2012Metric_Pad1.18x1.45mm_HandSolder
J3: SD_Card; SD_UNIVERSAL
R5, R6, R8, R9, R10, R11, R12, R50, R51: 10kΩ; R_0603_1608Metric_Pad0.98x0.95mm_HandSolder
U1: MIC2025-2YM; SOIC-8_3.9x4.9mm_P1.27mm

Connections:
/SD_CP: J3.10 (CARD_DETECT), R50.2; also elsewhere on the board
/SD_WP: J3.11 (WRITE_PROTECT), R51.2; also elsewhere on the board
/SPI1_CS: J3.1 (CD/DAT3), R9.2; also elsewhere on the board
/SPI1_MISO: J3.7 (DAT0), R11.2; also elsewhere on the board
/SPI1_MOSI: J3.2 (CMD), R10.2; also elsewhere on the board
/SPI1_SCK: J3.5 (CLK); also elsewhere on the board
GND: C3.1, C4.2, J3.3 (VSS), J3.6 (VSS), J3.12 (SHELL1), J3.13 (SHELL2), R6.2, U1.3 (GND); also elsewhere on the board
unnamed: J3.8 (DAT1), R12.2
unnamed: J3.9 (DAT2), R8.2

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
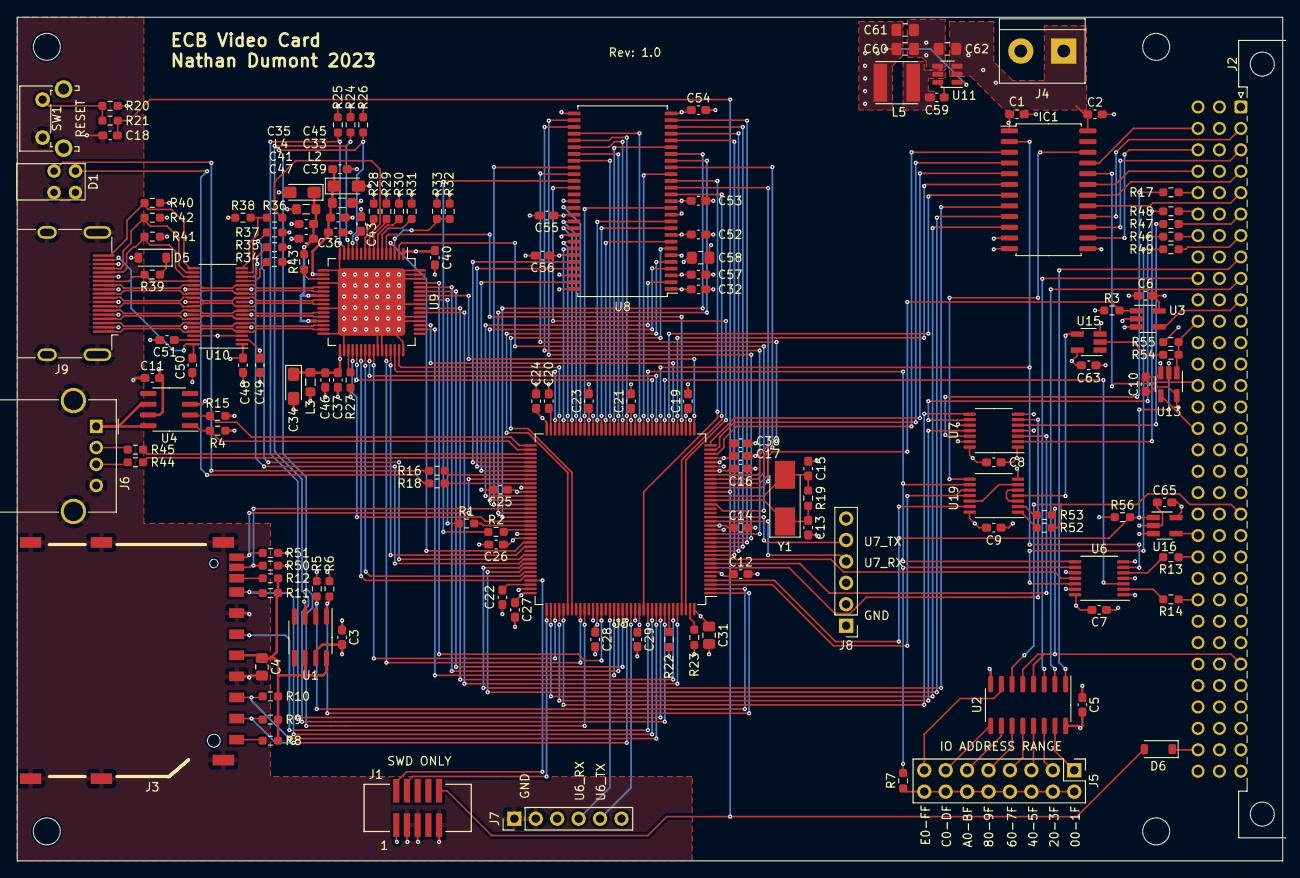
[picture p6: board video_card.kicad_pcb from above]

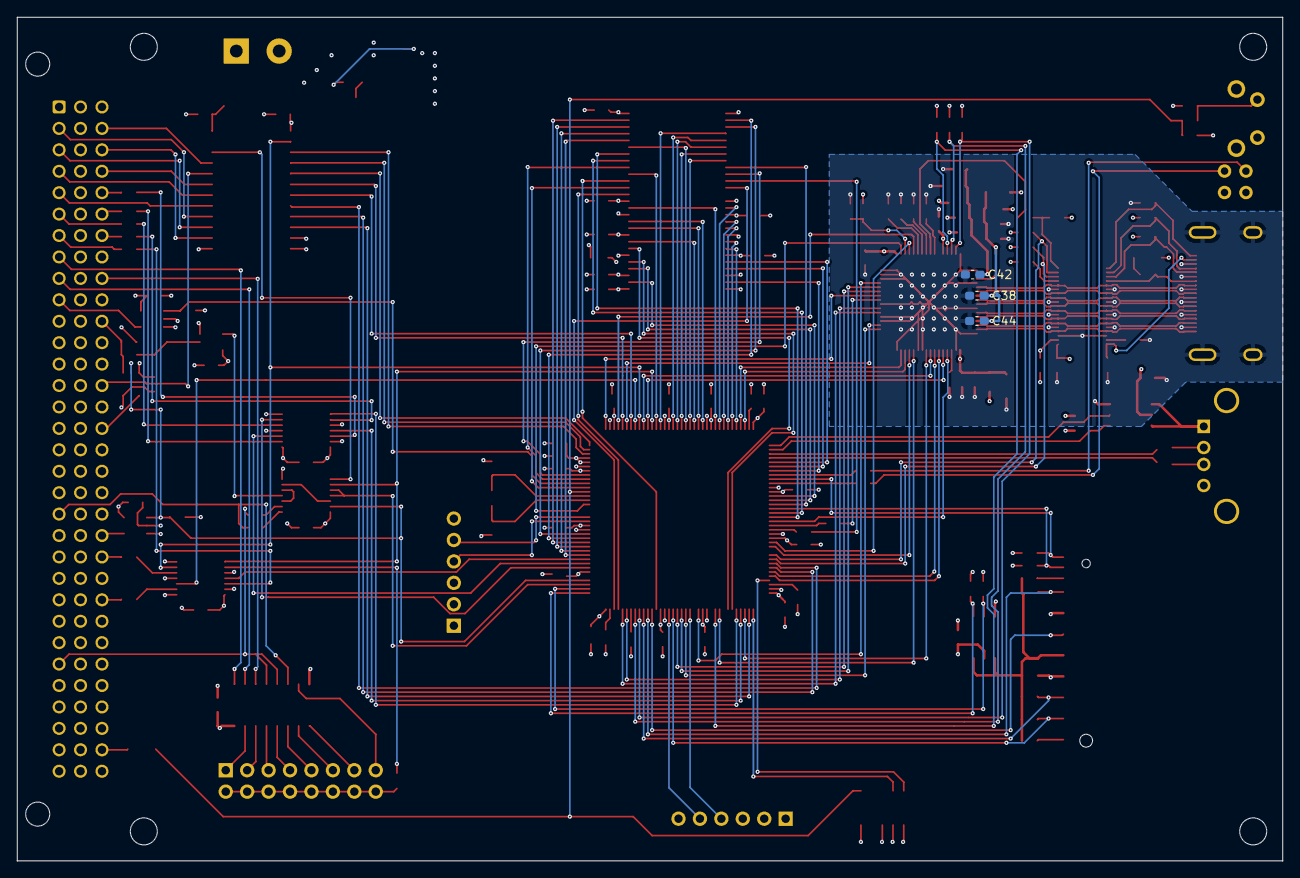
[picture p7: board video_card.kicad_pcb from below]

Board: 4 copper layers, 150.0 x 100.0 mm, 158 parts (3 on the bottom side), 205 nets.

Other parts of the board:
C11: 100nF; C_0603_1608Metric_Pad1.08x0.95mm_HandSolder
R4, R15, R55: 10kΩ; R_0603_1608Metric_Pad0.98x0.95mm_HandSolder
U4: MIC2025-2YM; SOIC-8_3.9x4.9mm_P1.27mm

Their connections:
GND: C11.1, R15.2, U4.3 (GND); also elsewhere on the board

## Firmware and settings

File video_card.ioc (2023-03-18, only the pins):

Mcu.UserName=STM32F429ZITx
PA0/WKUP.Signal=GPIO_Input
PA1.Signal=GPIO_Input
PA10.Signal=GPIO_Input
PA11.Signal=LTDC_R4
PA12.Signal=LTDC_R5
PA13.Signal=SYS_JTMS-SWDIO
PA14.Signal=SYS_JTCK-SWCLK
PA15.Signal=GPIO_Input
PA2.Signal=GPIO_Input
PA3.Signal=LTDC_B5
PA4.Signal=LTDC_VSYNC
PA5.Signal=GPIO_Input
PA6.Signal=LTDC_G2
PA7.Signal=GPIO_Input
PA8.Signal=I2C3_SCL
PA9.Signal=GPIO_Input
PB0.Signal=LTDC_R3
PB1.Signal=LTDC_R6
PB10.Signal=LTDC_G4
PB11.Signal=LTDC_G5
PB3.Signal=SPI1_SCK
PB4.Signal=SPI1_MISO
PB5.Signal=SPI1_MOSI
PB6.Signal=I2C1_SCL
PB7.Signal=I2C1_SDA
PB8.Signal=LTDC_B6
PB9.Signal=LTDC_B7
PC0.Signal=FMC_SDNWE
PC10.Signal=LTDC_R2
PC2.Signal=FMC_SDNE0
PC3.Signal=FMC_SDCKE0
PC6.Signal=LTDC_HSYNC
PC7.Signal=LTDC_G6
PC9.Signal=I2C3_SDA
PD0.Signal=FMC_D2_DA2
PD1.Signal=FMC_D3_DA3
PD10.Signal=FMC_D15_DA15
PD14.Signal=FMC_D0_DA0
PD15.Signal=FMC_D1_DA1
PD3.Signal=LTDC_G7
PD6.Signal=LTDC_B2
PD8.Signal=FMC_D13_DA13
PD9.Signal=FMC_D14_DA14
PE0.Signal=FMC_NBL0
PE1.Signal=FMC_NBL1
PE10.Signal=FMC_D7_DA7
PE11.Signal=FMC_D8_DA8
PE12.Signal=FMC_D9_DA9
PE13.Signal=FMC_D10_DA10
PE14.Signal=FMC_D11_DA11
PE15.Signal=FMC_D12_DA12
PE7.Signal=FMC_D4_DA4
PE8.Signal=FMC_D5_DA5
PE9.Signal=FMC_D6_DA6
PF0.Signal=FMC_A0
PF1.Signal=FMC_A1
PF10.Signal=LTDC_DE
PF11.Signal=FMC_SDNRAS
PF12.Signal=FMC_A6
PF13.Signal=FMC_A7
PF14.Signal=FMC_A8
PF15.Signal=FMC_A9
PF2.Signal=FMC_A2
PF3.Signal=FMC_A3
PF4.Signal=FMC_A4
PF5.Signal=FMC_A5
PF6.Signal=UART7_RX
PF7.Signal=UART7_TX
PG0.Signal=FMC_A10
PG1.Signal=FMC_A11
PG10.Signal=LTDC_G3
PG11.Signal=LTDC_B3
PG12.Signal=LTDC_B4
PG14.Signal=USART6_TX
PG15.Signal=FMC_SDNCAS
PG2.Signal=FMC_A12
PG4.Signal=FMC_A14_BA0
PG5.Signal=FMC_A15_BA1
PG6.Signal=LTDC_R7
PG7.Signal=LTDC_CLK
PG8.Signal=FMC_SDCLK
PG9.Signal=USART6_RX
PH0/OSC_IN.Signal=RCC_OSC_IN
PH1/OSC_OUT.Signal=RCC_OSC_OUT
